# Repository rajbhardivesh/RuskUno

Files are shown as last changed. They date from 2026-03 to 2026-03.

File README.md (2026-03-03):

# RuskUno — Arduino® alternative based on MindMotion MM32F0141C6P

**RuskUno** is an open-source development board designed as an Arduino-style alternative built around the MindMotion **MM32F0141C6P** (ARM Cortex-M0).  
This repo contains the KiCad hardware sources and initial documentation. An Arduino-style core / cores for this MCU is **in progress** and will be provided here when ready.

This repository contains:

- ✅ Full KiCad hardware source files
- 🚧 Arduino-compatible core (In Progress)
- 🔓 Open Source Hardware

---

# 📸 Development Board

## Top View
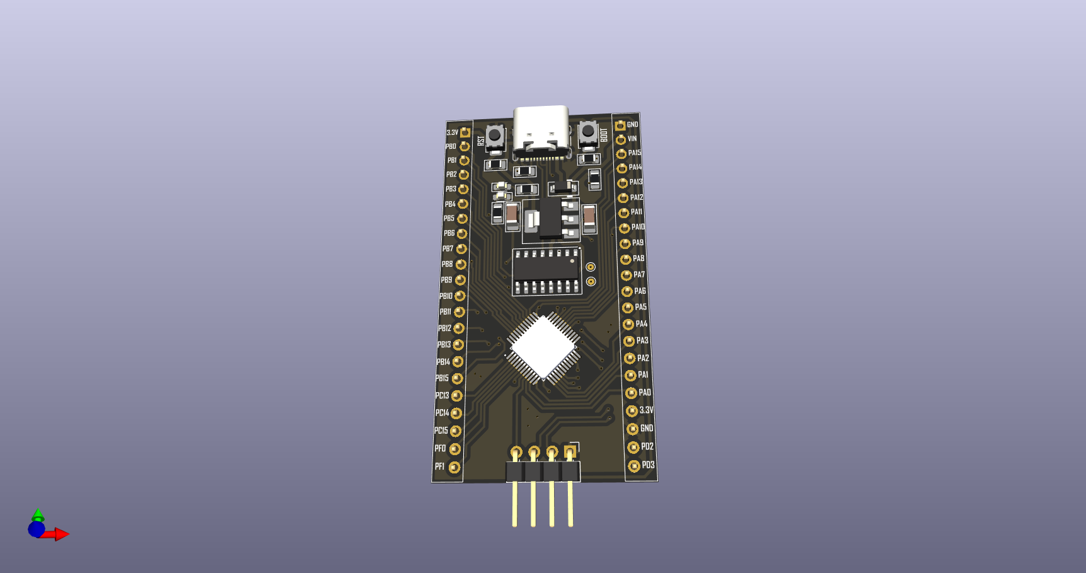
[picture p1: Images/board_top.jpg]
RuskUno Top


## Bottom View
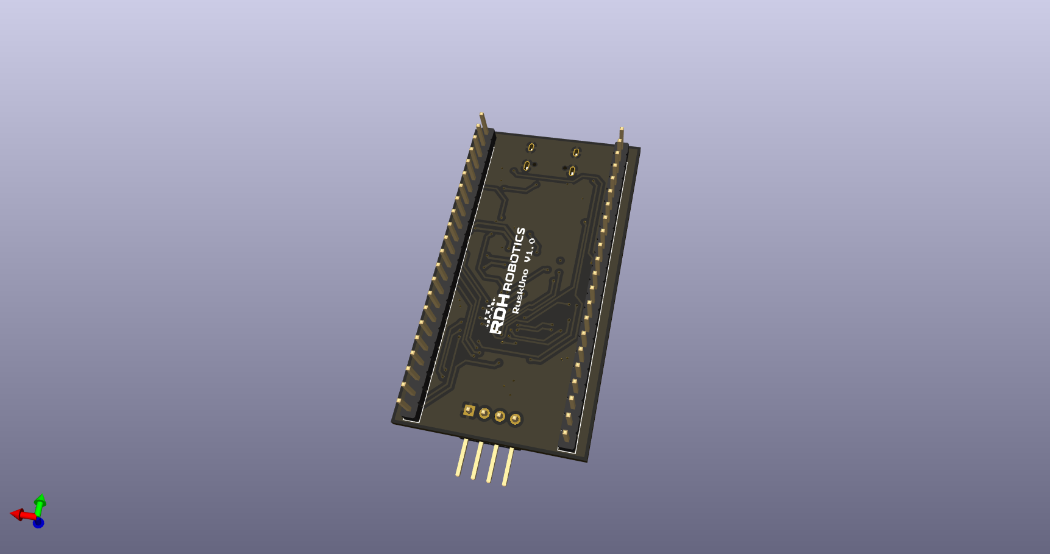
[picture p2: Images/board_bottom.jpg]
RuskUno Bottom


---

# 🧠 Why RuskUno?

The goal of RuskUno is to provide:

- Higher performance than ATmega328P
- More Flash & RAM
- Modern 32-bit ARM architecture
- Open hardware design
- Future Arduino ecosystem compatibility
- Affordable alternative for students & developers

---

# ⚙️ Microcontroller Overview

## 🔹 MM32F0141C6P

- Core: ARM Cortex-M0 (32-bit)
- Max Clock: 72 MHz
- Flash: 64 KB
- SRAM: 8 KB
- Multiple UART / SPI / I2C
- 12-bit ADC
- Advanced Timers
- SWD Debug Support

---

# 🔄 Comparison: MM32F0141C6P vs ATmega328P

| Feature | MM32F0141C6P | ATmega328P |
|---|---|---|
| Architecture | 32-bit ARM Cortex-M0 | 8-bit AVR |
| Max Frequency | 72 MHz | 20 MHz |
| Flash | 64 KB | 32 KB |
| SRAM | 8 KB | 2 KB |
| ADC | 12-bit | 10-bit |
| Debug | SWD | No native debugger |
| Performance | High | Moderate |
| Math Speed | Fast 32-bit | Slower 8-bit |

**Result:**  
RuskUno offers significantly better performance, memory headroom, and peripheral flexibility compared to traditional Arduino UNO.

---

# 🛠 Hardware Features

- Arduino-style pin header layout
- USB programming interface
- External crystal
- SWD debug header
- 3.3V logic
- Power via USB or VIN
- LDO regulator onboard
- Status LED
- Reset button

---

# 🧩 Arduino Core (In Progress)

The Arduino-compatible core is currently under development.

Planned features:
- Arduino pin mapping
- digitalWrite / digitalRead
- analogRead
- PWM
- Serial support
- SPI & I2C
- Timer support

Once stable, the core will be:
- Added in `/firmware`
- Packaged for Arduino IDE board manager

Stay tuned ⭐

---

# 🎯 Project Vision

RuskUno aims to:

- Provide a powerful yet affordable board for students
- Enable migration from 8-bit AVR to 32-bit ARM easily
- Offer fully open hardware
- Support embedded learners
- Build an ecosystem around MM32 microcontrollers

---

# 🤝 Contributing

Pull requests are welcome!

If you'd like to contribute:
1. Fork the repository
2. Create a feature branch
3. Commit your changes
4. Submit a PR

---

# 📌 Roadmap

- [x] Hardware Design Complete
- [x] Prototype Built
- [ ] Arduino Core Development
- [ ] Bootloader
- [ ] Documentation Expansion
- [ ] Example Projects

---

# 🌍 Open Hardware Commitment

RuskUno is 100% open-source.

KiCad files are provided.
Anyone can:
- Study
- Modify
- Manufacture
- Improve

---

# 👨‍💻 Author

Designed & Developed by  
**Rajbhar Divesh**

---

# 🔓 License

This project is licensed under the MIT License.

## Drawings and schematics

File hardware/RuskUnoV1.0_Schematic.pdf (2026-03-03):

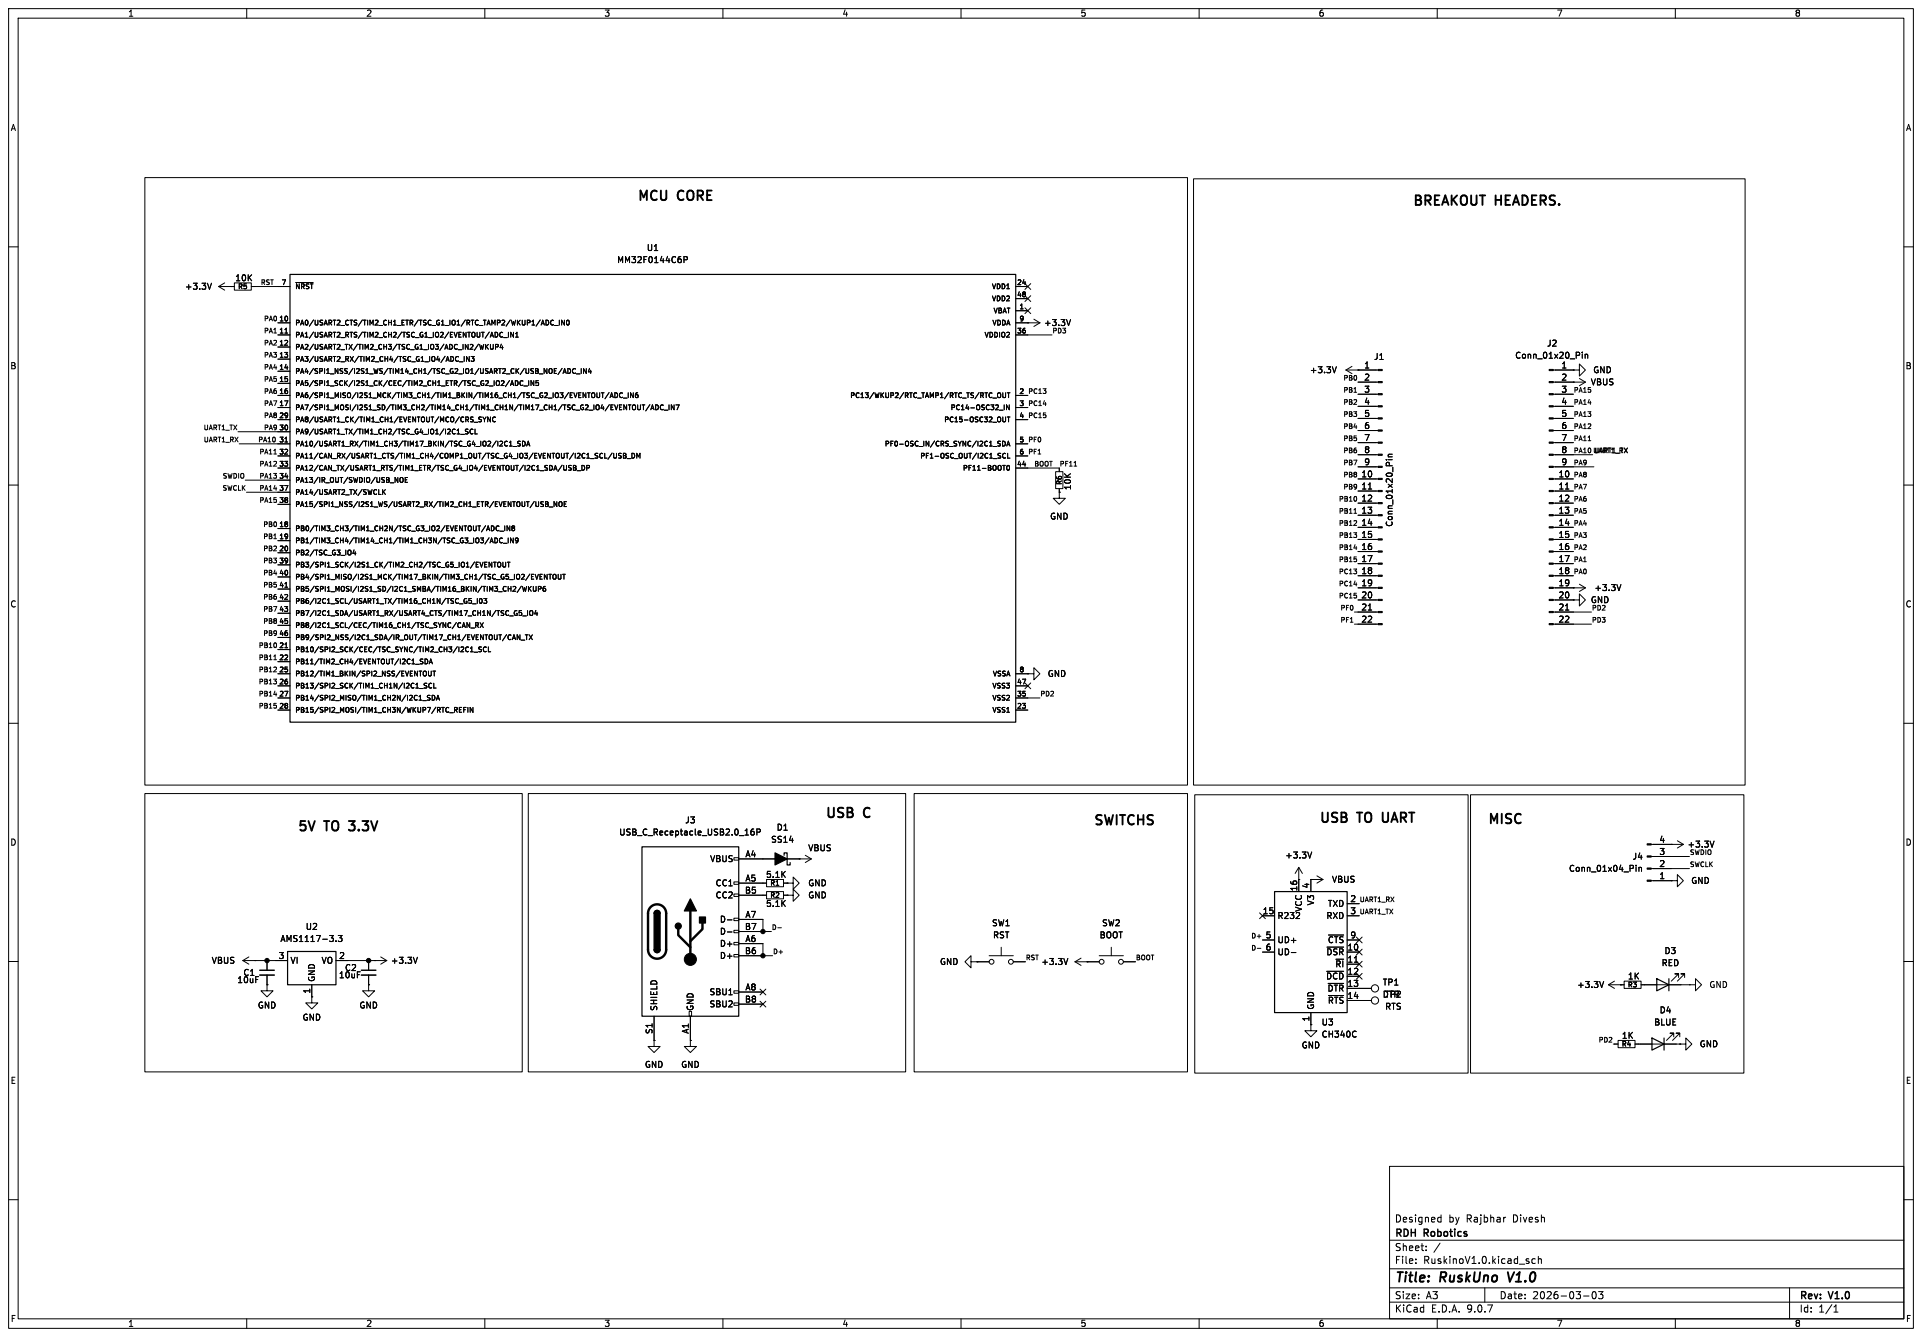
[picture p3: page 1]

1 TXD 2 RXD 3 ~{CTS}9 ~{DSR} 10 ~{RI} 11 ~{DCD} 12 ~{DTR} 13 ~{RTS} 14 VBUS GND

1 TXD 2 RXD 3 ~{CTS}9 ~{DSR} 10 ~{RI} 11 ~{DCD} 12 ~{DTR} 13 ~{RTS} 14 U3 CH340C

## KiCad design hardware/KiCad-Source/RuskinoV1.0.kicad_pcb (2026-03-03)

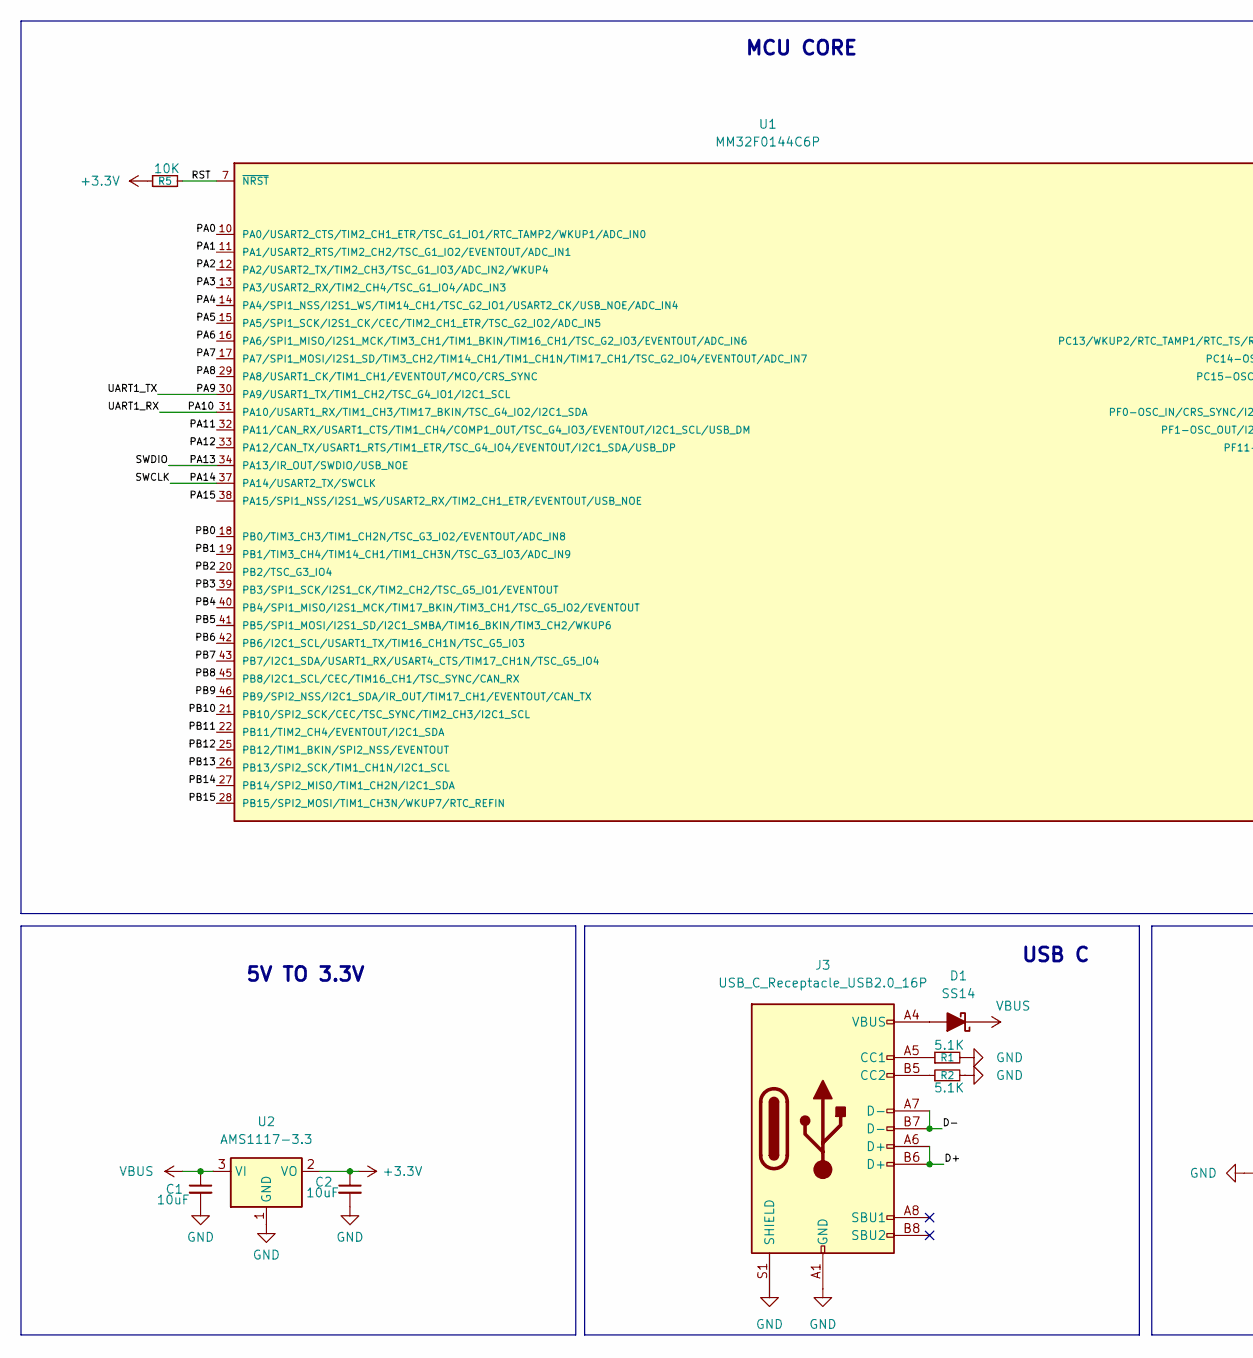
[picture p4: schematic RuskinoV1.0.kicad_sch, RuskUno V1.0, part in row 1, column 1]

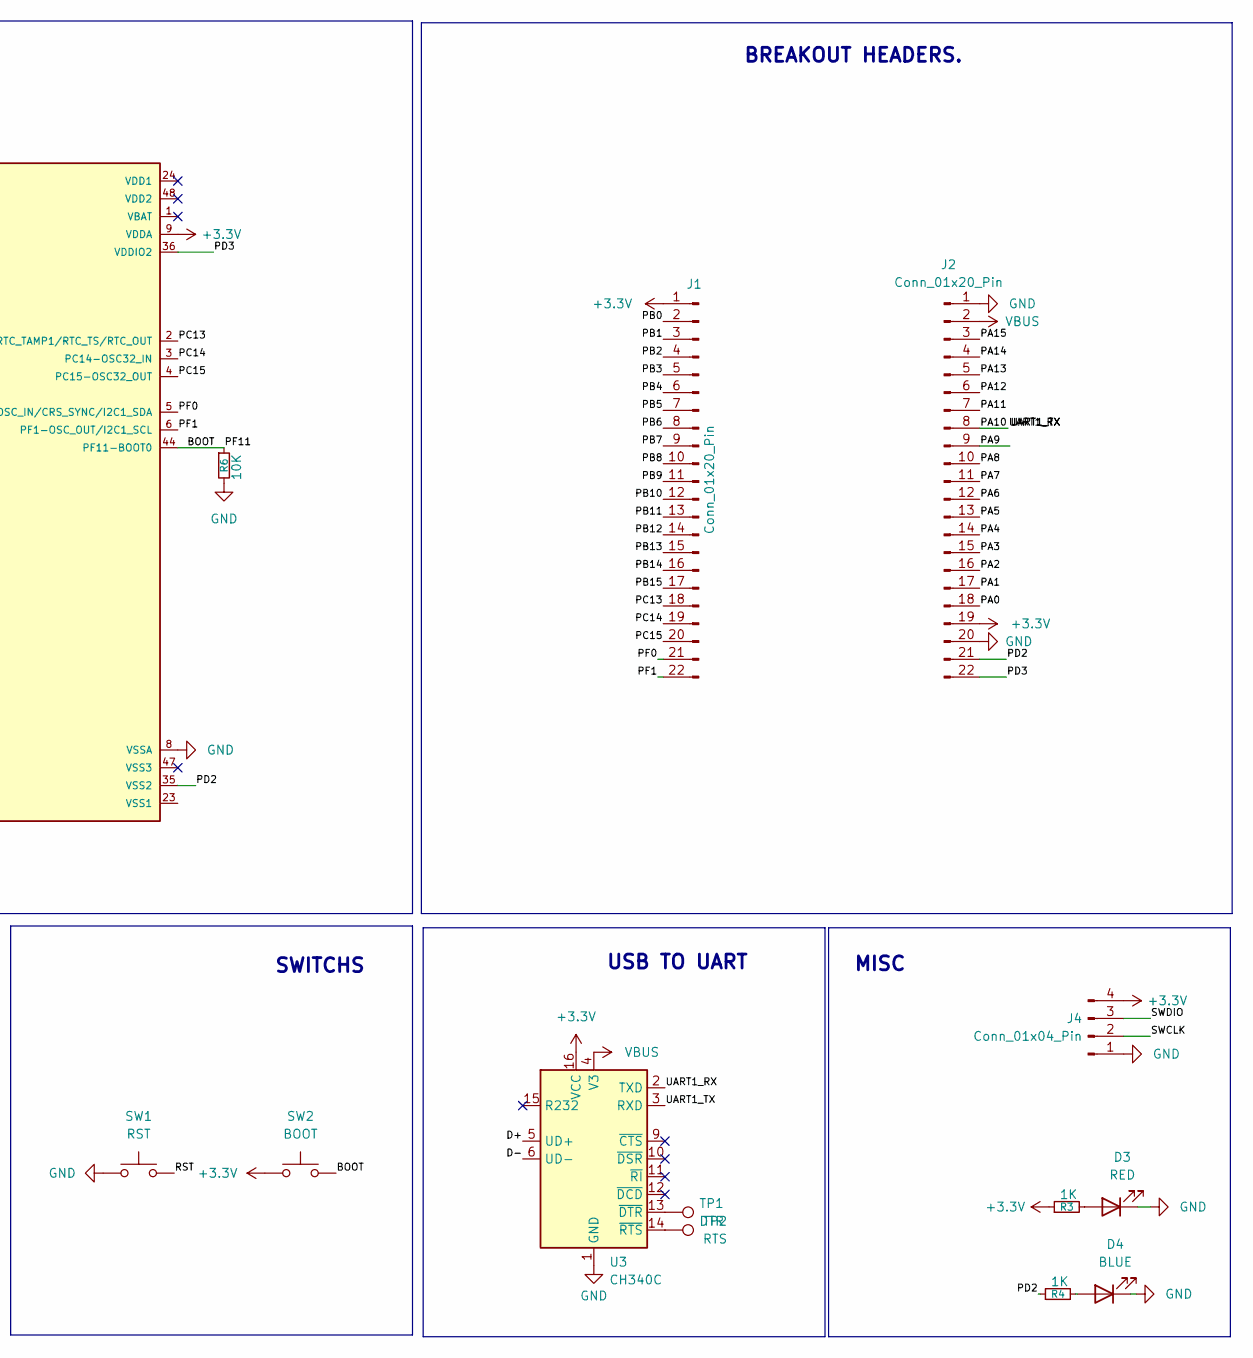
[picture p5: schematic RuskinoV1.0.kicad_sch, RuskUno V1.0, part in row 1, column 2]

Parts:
C1, C2: 10uF; C_1206_3216Metric_Pad1.33x1.80mm_HandSolder
D1: SS14; D_SOD-123
D3: RED; LED_0603_1608Metric_Pad1.05x0.95mm_HandSolder
D4: BLUE; LED_0603_1608Metric_Pad1.05x0.95mm_HandSolder
J1, J2: Conn_01x20_Pin; PinHeader_1x22_P2.54mm_Vertical
J3: USB_C_Receptacle_USB2.0_16P; USB_C_Receptacle_GCT_USB4105-xx-A_16P_TopMnt_Horizontal
J4: Conn_01x04_Pin; PinHeader_1x04_P2.54mm_Horizontal
R1, R2: 5.1K; R_0805_2012Metric_Pad1.15x1.40mm_HandSolder
R3, R4: 1K; R_0805_2012Metric_Pad1.15x1.40mm_HandSolder
R5, R6: 10K; R_0805_2012Metric_Pad1.15x1.40mm_HandSolder
SW1: RST; SW_SPST_TS-1088-xR020
SW2: BOOT; SW_SPST_TS-1088-xR020
TP1: DTR; TestPoint_Pad_D1.0mm
TP2: RTS; TestPoint_Pad_D1.0mm
U1: MM32F0144C6P; QFP50P700X700X160-48N
U2: AMS1117-3.3; SOT-223-3_TabPin2
U3: CH340C; SOIC-16_3.9x9.9mm_P1.27mm

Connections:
+3.3V: C2.1, J1.1, J2.19, J4.4, R3.1, R5.1, SW2.1, U1.9 (VDDA), U2.2 (VO), U3.16 (VCC)
/BOOT: R6.1, SW2.2, U1.44 (PF11-BOOT0)
/D+: J3.A6 (D+), J3.B6 (D+), U3.5 (UD+)
/D-: J3.A7 (D-), J3.B7 (D-), U3.6 (UD-)
/PA0: J2.18, U1.10 (PA0/USART2_CTS/TIM2_CH1_ETR/TSC_G1_IO1/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)
/PA1: J2.17, U1.11 (PA1/USART2_RTS/TIM2_CH2/TSC_G1_IO2/EVEN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)
/PA2: J2.16, U1.12 (PA2/USART2_TX/TIM2_CH3/TSC_G1_IO3/ADC_I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)
/PA3: J2.15, U1.13 (PA3/USART2_RX/TIM2_CH4/TSC_G1_IO4/ADC_I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)
/PA4: J2.14, U1.14 (PA4/SPI1_NSS/I2S1_WS/TIM14_CH1/TSC_G2_I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)
/PA5: J2.13, U1.15 (PA5/SPI1_SCK/I2S1_CK/CEC/TIM2_CH1_ETR/T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)
/PA6: J2.12, U1.16 (PA6/SPI1_MISO/I2S1_MCK/TIM3_CH1/TIM1_BK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)
/PA7: J2.11, U1.17 (PA7/SPI1_MOSI/I2S1_SD/TIM3_CH2/TIM14_CH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)
/PA8: J2.10, U1.29 (PA8/USART1_CK/TIM1_CH1/EVENTOUT/MCO/CRS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)
/PA9: J2.9, U1.30 (PA9/USART1_TX/TIM1_CH2/TSC_G4_IO1/I2C1_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), U3.3 (RXD)
/PA10: J2.8, U1.31 (PA10/USART1_RX/TIM1_CH3/TIM17_BKIN/TSC_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), U3.2 (TXD)
/PA11: J2.7, U1.32 (PA11/CAN_RX/USART1_CTS/TIM1_CH4/COMP1_O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)
/PA12: J2.6, U1.33 (PA12/CAN_TX/USART1_RTS/TIM1_ETR/TSC_G4_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)
/PA13: J2.5, J4.3, U1.34 (PA13/IR_OUT/SWDIO/USB_NOE)
/PA14: J2.4, J4.2, U1.37 (PA14/USART2_TX/SWCLK)
/PA15: J2.3, U1.38 (PA15/SPI1_NSS/I2S1_WS/USART2_RX/TIM2_CH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)
/PB0: J1.2, U1.18 (PB0/TIM3_CH3/TIM1_CH2N/TSC_G3_IO2/EVENT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)
/PB1: J1.3, U1.19 (PB1/TIM3_CH4/TIM14_CH1/TIM1_CH3N/TSC_G3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)
/PB2: J1.4, U1.20 (PB2/TSC_G3_IO4)
/PB3: J1.5, U1.39 (PB3/SPI1_SCK/I2S1_CK/TIM2_CH2/TSC_G5_IO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)
/PB4: J1.6, U1.40 (PB4/SPI1_MISO/I2S1_MCK/TIM17_BKIN/TIM3_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)
/PB5: J1.7, U1.41 (PB5/SPI1_MOSI/I2S1_SD/I2C1_SMBA/TIM16_B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)
/PB6: J1.8, U1.42 (PB6/I2C1_SCL/USART1_TX/TIM16_CH1N/TSC_G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)
/PB7: J1.9, U1.43 (PB7/I2C1_SDA/USART1_RX/USART4_CTS/TIM17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)
/PB8: J1.10, U1.45 (PB8/I2C1_SCL/CEC/TIM16_CH1/TSC_SYNC/CAN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)
/PB9: J1.11, U1.46 (PB9/SPI2_NSS/I2C1_SDA/IR_OUT/TIM17_CH1/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)
/PB10: J1.12, U1.21 (PB10/SPI2_SCK/CEC/TSC_SYNC/TIM2_CH3/I2C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)
/PB11: J1.13, U1.22 (PB11/TIM2_CH4/EVENTOUT/I2C1_SDA)
/PB12: J1.14, U1.25 (PB12/TIM1_BKIN/SPI2_NSS/EVENTOUT)
/PB13: J1.15, U1.26 (PB13/SPI2_SCK/TIM1_CH1N/I2C1_SCL)
/PB14: J1.16, U1.27 (PB14/SPI2_MISO/TIM1_CH2N/I2C1_SDA)
/PB15: J1.17, U1.28 (PB15/SPI2_MOSI/TIM1_CH3N/WKUP7/RTC_REFIN)
/PC13: J1.18, U1.2 (PC13/WKUP2/RTC_TAMP1/RTC_TS/RTC_OUT)
/PC14: J1.19, U1.3 (PC14-OSC32_IN)
/PC15: J1.20, U1.4 (PC15-OSC32_OUT)
/PD2: J2.21, R4.1, U1.35 (VSS2)
/PD3: J2.22, U1.36 (VDDIO2)
/PF0: J1.21, U1.5 (PF0-OSC_IN/CRS_SYNC/I2C1_SDA)
/PF1: J1.22, U1.6 (PF1-OSC_OUT/I2C1_SCL)
/RST: R5.2, SW1.2, U1.7 (~NRST)
GND: C1.2, C2.2, D3.1 (K), D4.1 (K), J2.1, J2.20, J3.A1 (GND), J3.A12 (GND), J3.B1 (GND), J3.B12 (GND), J3.S1 (SHIELD), J4.1, R1.2, R2.2, R6.2, SW1.1, U1.8 (VSSA), U2.1 (GND), U3.1 (GND)
unnamed: D1.2 (A), J3.A4 (VBUS), J3.A9 (VBUS), J3.B4 (VBUS), J3.B9 (VBUS)
unnamed: D3.2 (A), R3.2
unnamed: D4.2 (A), R4.2
unnamed: J3.A5 (CC1), R1.1
unnamed: J3.B5 (CC2), R2.1
unnamed: TP1.1, U3.13 (~DTR)
unnamed: TP2.1, U3.14 (~RTS)
VBUS: C1.1, D1.1 (K), J2.2, U2.3 (VI), U3.4 (V3)

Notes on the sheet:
MISC
USB TO UART
5V TO 3.3V
BREAKOUT HEADERS.
MCU CORE
USB C
SWITCHS

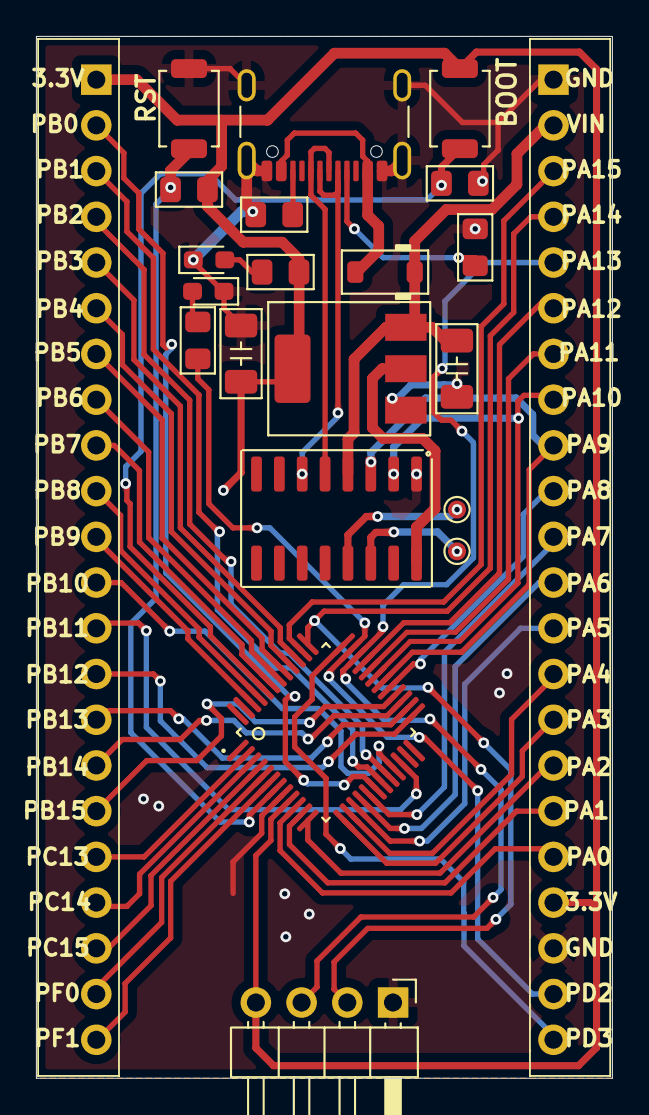
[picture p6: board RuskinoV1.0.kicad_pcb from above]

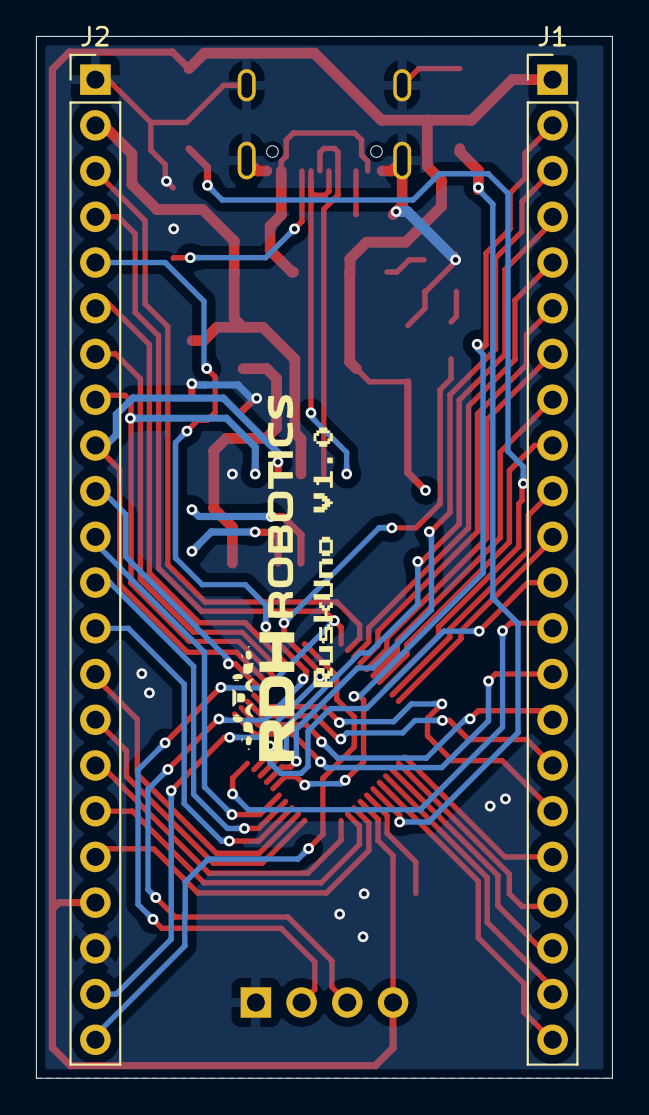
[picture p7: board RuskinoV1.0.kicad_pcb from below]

Board: 2 copper layers, 32.0 x 57.9 mm, 22 parts (2 on the bottom side), 53 nets.
